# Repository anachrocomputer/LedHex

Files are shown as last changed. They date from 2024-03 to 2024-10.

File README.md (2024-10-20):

# LedHex #

This repository contains several programs to run on an Arduino
and drive a display made from LEDs.

The display was made as a small-volume low-cost PCB using a design drawn in KiCad.

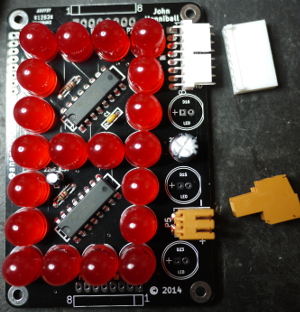
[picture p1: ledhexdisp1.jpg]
LedHexDisplay Completed PCB populated with red LEDs


## KiCadV3Pcb ##

CAD files for the schematic and PCB,
designed in 2014 using KiCad V3.
This version of KiCad is so old now that it's not practical to update the files.
At the time of writing,
KiCad is at V8.0.5 and uses a completely different set of PCB footprints from V3.
So although it's possible to update the schematic files to use the latest format
and the latest symbols,
it's difficult to map those symbols to the new footprints.
This means that the PCB layout cannot be resynchronised with the schematic.
Probably the easiest way to fix this would be to re-draw in KiCad V8.

The schematic is shown as a PDF for reference when writing software
to drive the display.

## LedHexClock ##

Very simple four-digit clock with flashing colon.
So simple, in fact,
that there's no way to set the time.

TODO: add a way to set the time.

TODO: add 12/24 hour switch.

TODO: add other types of time display, TBD.

## LedHexCount4 ##

Display a four-digit counter on four LedHex PCBs connected in a chain.
Range is 0000-FFFF (0-65535).

## LedHexLampTest4 ##

Test a four-digit chain of LedHex PCBs by lighting up all the segments
in sequence.
This is also a test of the LED power supply!

## LedHexTest ##

Simply count 0-9, A-F repeatedly on a single digit display.

## LedHexTest4 ##

Test a four-digit chain of LedHex PCBs by lighting up all the segments
in sequence.

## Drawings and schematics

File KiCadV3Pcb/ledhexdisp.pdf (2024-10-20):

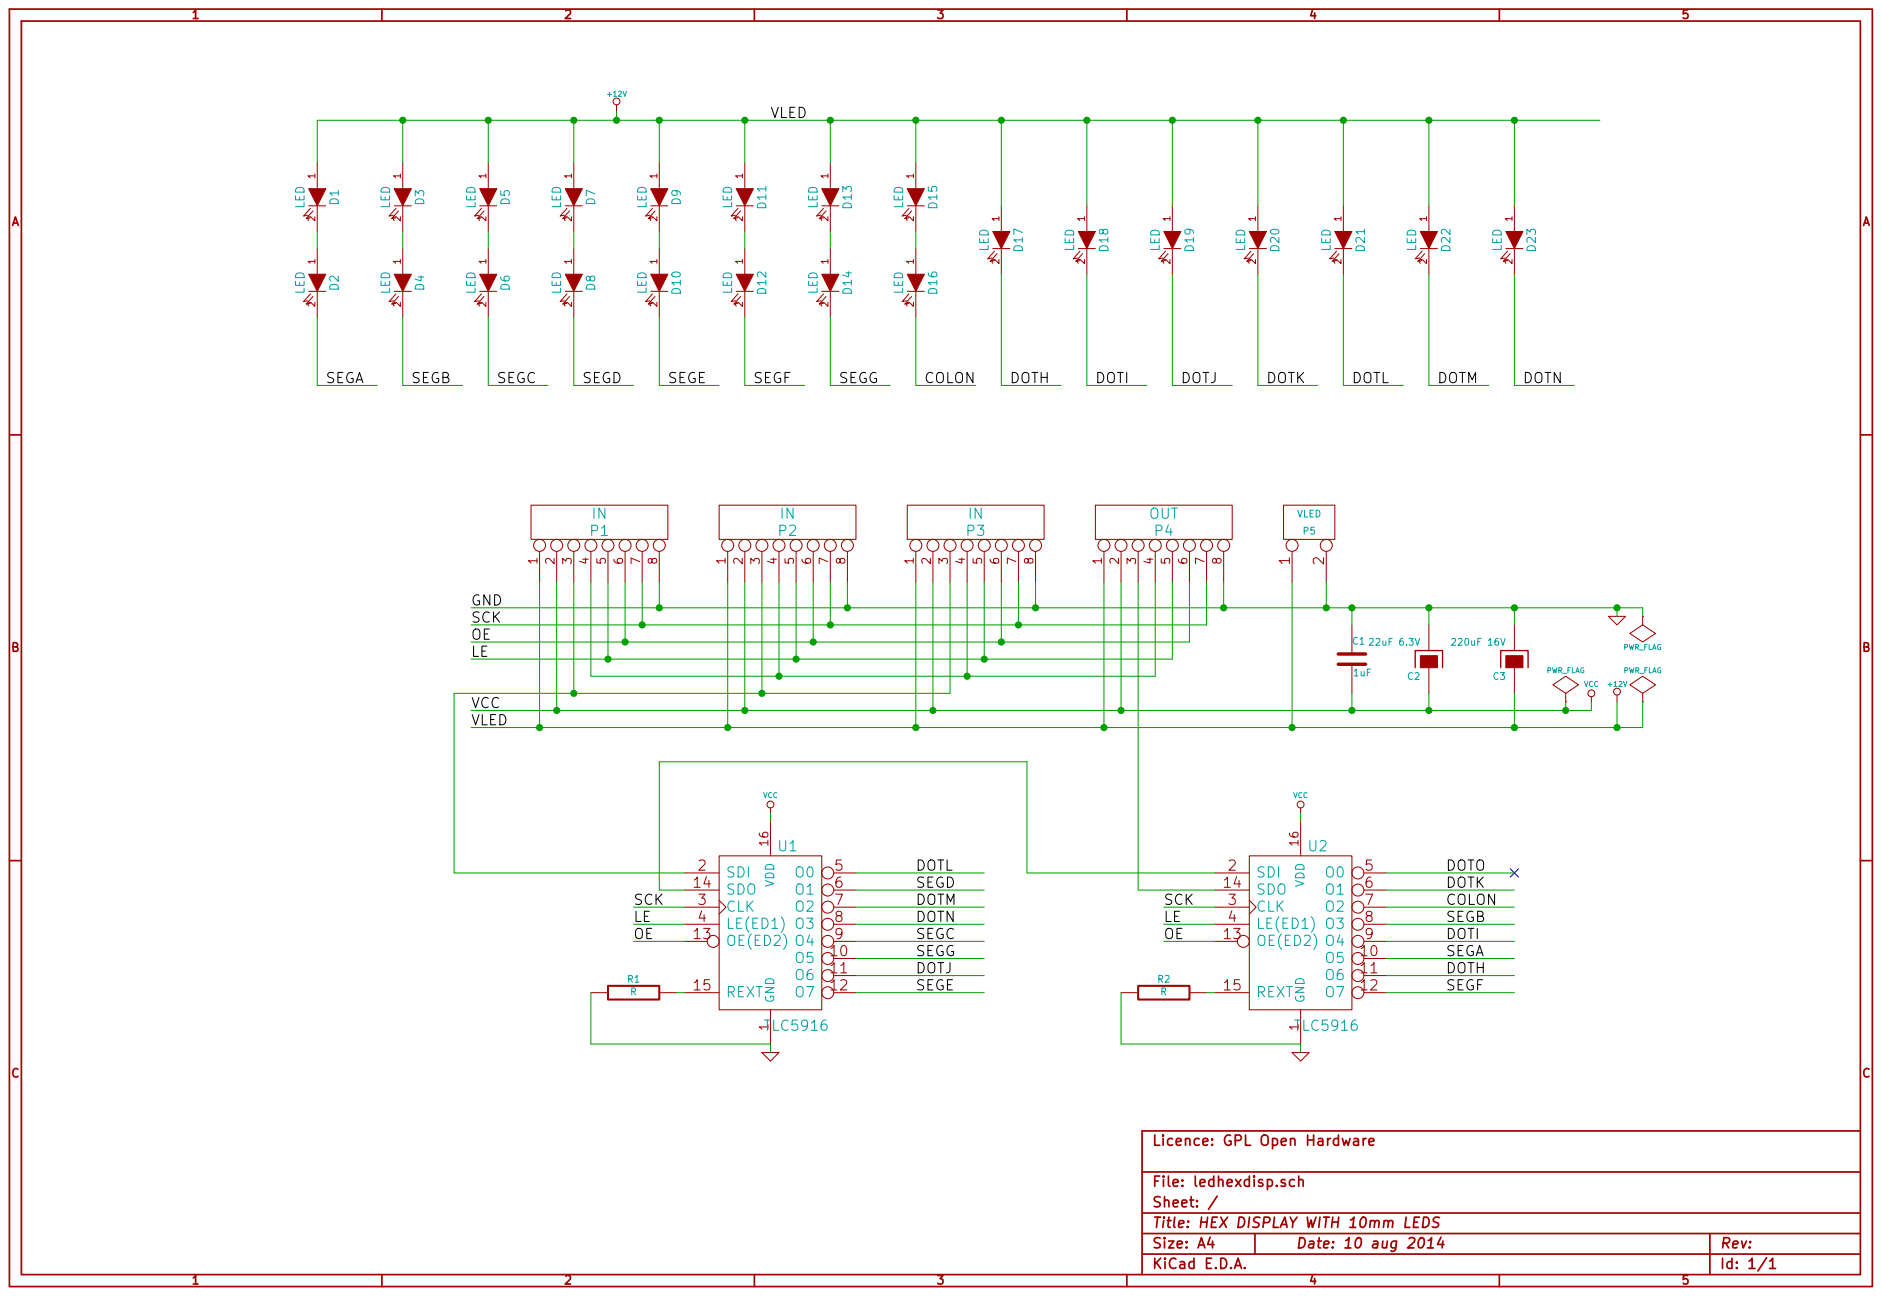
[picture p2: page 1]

Licence: GPL Open Hardware

File: ledhexdisp.sch
Sheet: /
Title: HEX DISPLAY WITH 10mm LEDS
KiCad E.D.A.

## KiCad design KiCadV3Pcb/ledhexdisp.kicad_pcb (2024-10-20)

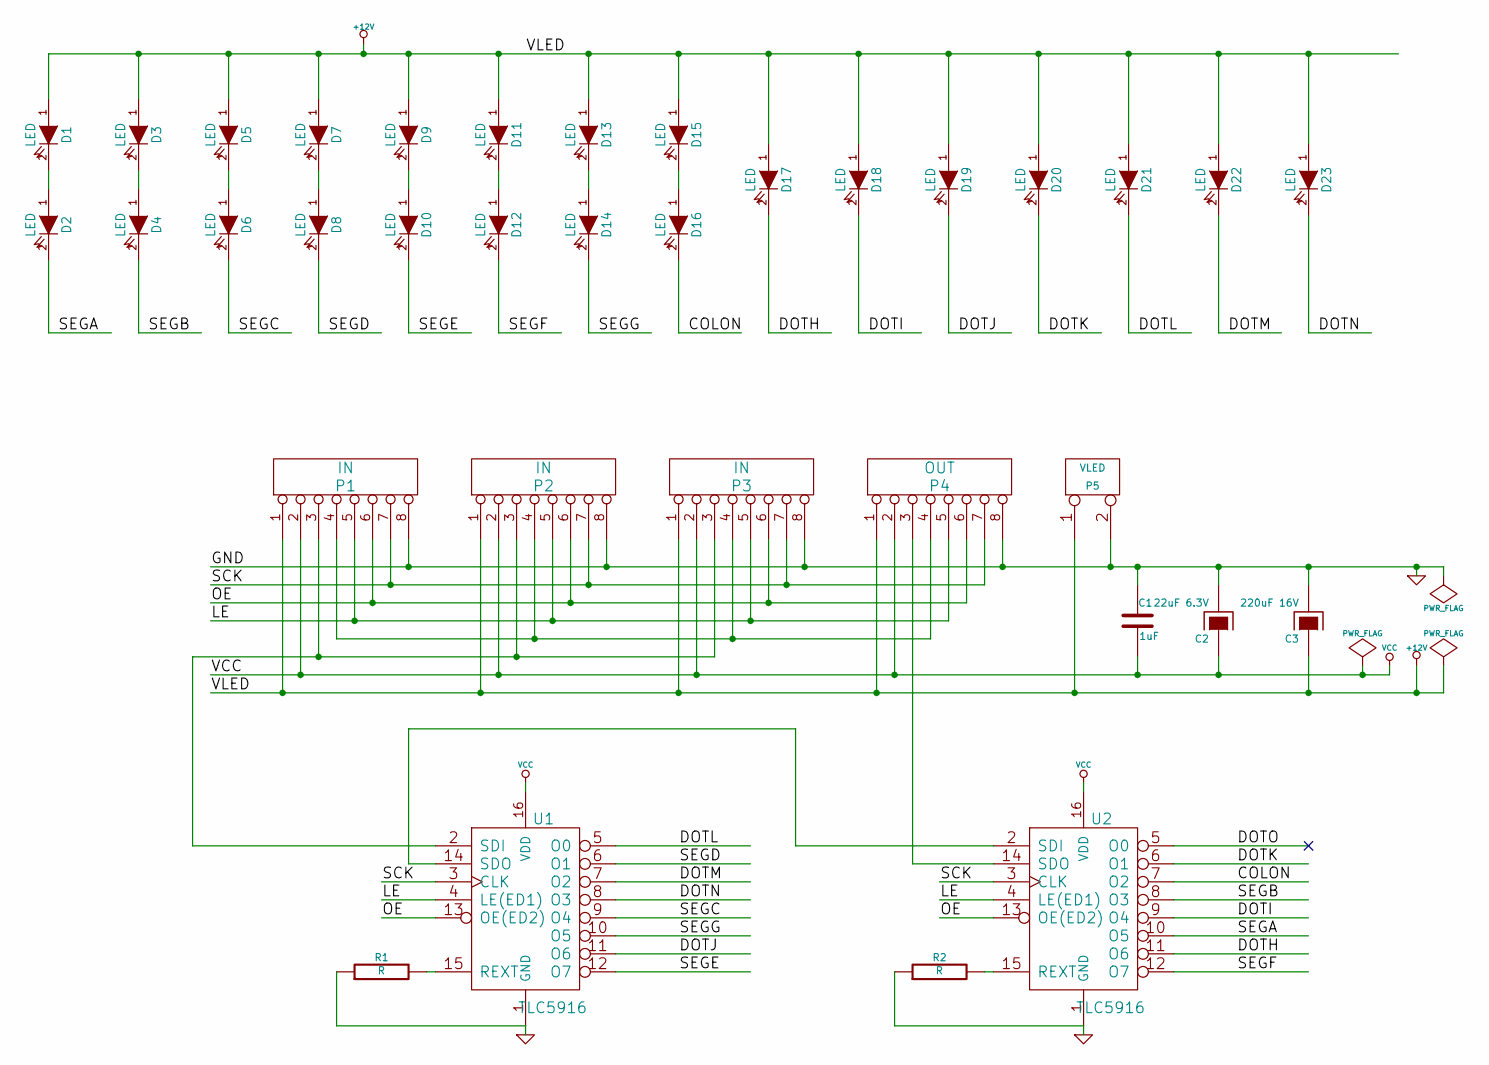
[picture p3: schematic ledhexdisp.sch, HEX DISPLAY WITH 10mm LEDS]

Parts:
C1: 1uF
C2: 22uF 6.3V
C3: 220uF 16V
D1, D2, D3, D4, D5, D6, D7, D8, D9, D10, D11, D12, D13, D14, D15, D16, D17, D18, D19, D20, D21, D22, D23: LED
P1, P2, P3: IN
P4: OUT
P5: VLED
R1, R2: R
U1, U2: TLC5916

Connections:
+12V: C3.1, D1.1 (A), D3.1 (A), D5.1 (A), D7.1 (A), D9.1 (A), D11.1 (A), D13.1 (A), D15.1 (A), D17.1 (A), D18.1 (A), D19.1 (A), D20.1 (A), D21.1 (A), D22.1 (A), D23.1 (A), P1.1, P2.1, P3.1, P4.1, P5.1
/COLON: D16.2 (K), U2.7 (O2)
/DOTH: D17.2 (K), U2.11 (O6)
/DOTI: D18.2 (K), U2.9 (O4)
/DOTJ: D19.2 (K), U1.11 (O6)
/DOTK: D20.2 (K), U2.6 (O1)
/DOTL: D21.2 (K), U1.5 (O0)
/DOTM: D22.2 (K), U1.7 (O2)
/DOTN: D23.2 (K), U1.8 (O3)
/LE: P1.5, P2.5, P3.5, P4.5, U1.4 (LE(ED1)), U2.4 (LE(ED1))
/OE: P1.6, P2.6, P3.6, P4.6, U1.13 (OE(ED2)), U2.13 (OE(ED2))
/SCK: P1.7, P2.7, P3.7, P4.7, U1.3 (CLK), U2.3 (CLK)
/SEGA: D2.2 (K), U2.10 (O5)
/SEGB: D4.2 (K), U2.8 (O3)
/SEGC: D6.2 (K), U1.9 (O4)
/SEGD: D8.2 (K), U1.6 (O1)
/SEGE: D10.2 (K), U1.12 (O7)
/SEGF: D12.2 (K), U2.12 (O7)
/SEGG: D14.2 (K), U1.10 (O5)
GND: C1.1, C2.2, C3.2, P1.8, P2.8, P3.8, P4.8, P5.2 (PM), R1.1, R2.1, U1.1 (GND), U2.1 (GND)
unnamed: D5.2 (K), D6.1 (A)
unnamed: D3.2 (K), D4.1 (A)
unnamed: R2.2, U2.15 (REXT)
unnamed: D15.2 (K), D16.1 (A)
unnamed: D13.2 (K), D14.1 (A)
unnamed: D11.2 (K), D12.1 (A)
unnamed: D9.2 (K), D10.1 (A)
unnamed: D7.2 (K), D8.1 (A)
unnamed: R1.2, U1.15 (REXT)
unnamed: P4.3, U2.14 (SDO)
unnamed: P1.3, P2.3, P3.3, U1.2 (SDI)
unnamed: U1.14 (SDO), U2.2 (SDI)
unnamed: P1.4, P2.4, P3.4, P4.4
unnamed: D1.2 (K), D2.1 (A)
VCC: C1.2, C2.1, P1.2, P2.2, P3.2, P4.2, U1.16 (VDD), U2.16 (VDD)

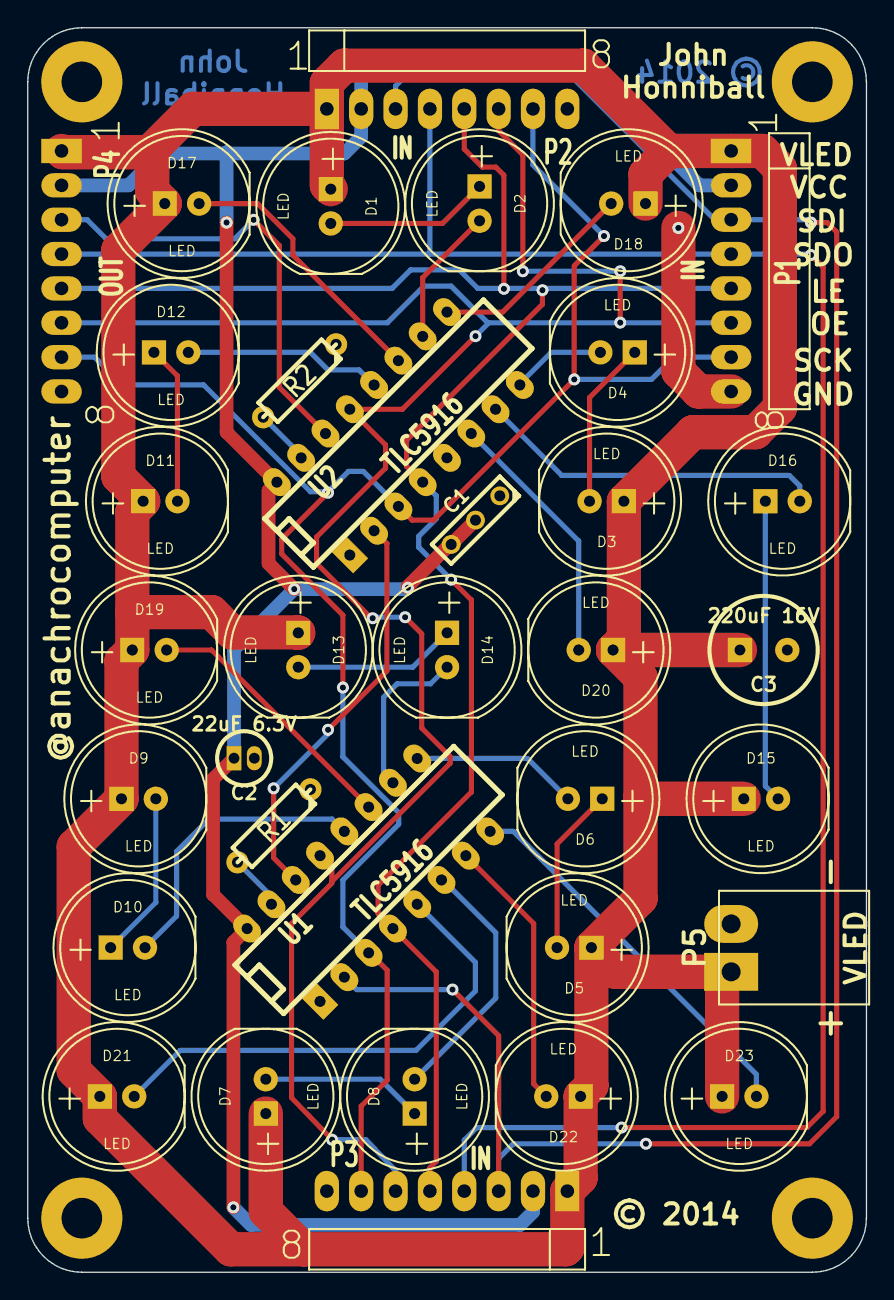
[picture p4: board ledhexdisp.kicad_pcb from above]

Board: 2 copper layers, 62.0 x 92.0 mm, 35 parts (0 on the bottom side), 35 nets.

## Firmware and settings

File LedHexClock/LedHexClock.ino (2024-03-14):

/* LedHexClock --- display a four-digit clock             2018-02-18 */
/* Copyright (c) 2018 John Honniball                                 */

#define NDIGITS    (4)   // This program uses a four-digit display

// Pin connections from LED board to Arduino board
// 1 VLED +5V (LED power, OK to use Arduino +5V for a single digit)
// 2 VCC  +5V (TLC5916 chip power)
// 3 SDI  D11 (Serial Data In on TLC5916)
// 4 SDO  no connection (Serial Data out on TLC5916, unused)
// 5 LE   D10 (Latch Enable on TLC5916)
// 6 OE   GND (Output Enable, unused in this test, GND to enable)
// 7 SCK  D13 (Serial Clock to TLC5916)
// 8 GND  GND (Ground to both LEDs and chip)
//
#define LE_PIN 10   // Arduino digital pin 10
#define SDA_PIN 11  // Arduino digital pin 11
#define SCK_PIN 13  // Arduino digital pin 13
/* OE pin grounded */

// 'F' is #defined as a macro by Arduino framework. Use an int instead
const int F = (1 << 14);

// Usual 7-segment names
#define A  (1 << 8)
#define B  (1 << 0)
#define C  (1 << 2)
#define D  (1 << 4)
#define E  (1 << 11)
//#define F  (1 << 14)
#define G  (1 << 10)
#define DP (1 << 12)

// Additional dot names
#define H (1 << 1)
#define I (1 << 3)
#define J (1 << 9)
#define K (1 << 6)
#define L (1 << 15)
#define M (1 << 13)
#define COLON (1 << 5)

// LED layout on PCB:
//
//     H C C I
//     B     D
//     B     D
//     J G G K
//     A     E
//     A     E
//     L F F M DP

// Table of 14-segment digits 0-9 and A-F
const unsigned int HDSPsegtab[16] = {
  A | B | C | D | E | F | J | K,         // 0
  D | E | I | K | M,                     // 1
  A | C | D | F | G | H | L | M,         // 2
  C | D | E | F | G | H | L,             // 3
  B | D | E | G | H | J | K | M,         // 4
  B | C | E | F | G | H | I | J | L,     // 5
  A | B | C | E | F | G | J,             // 6
  C | D | E | H | I | K | M,             // 7
  A | B | C | D | E | F | G,             // 8
  B | C | D | E | F | G | K,             // 9
  A | B | C | D | E | G | J | K | L | M, // A
  A | B | C | D | E | F | G | H | J | L, // B
  A | B | C | F | I | J | M,             // C
  A | B | C | D | E | F | H | J | K | L, // D
  A | B | C | F | G | H | I | J | L | M, // E
  A | B | C | G | H | I | J | L          // F
};


void setup(void)
{
  pinMode(LE_PIN, OUTPUT);
  pinMode(SDA_PIN, OUTPUT);
  pinMode(SCK_PIN, OUTPUT);
  
  digitalWrite(LE_PIN, LOW);
  digitalWrite(SCK_PIN, LOW);
}


void loop(void)
{
  int d;
  unsigned int hours = 12, minutes = 0;
  unsigned int frames = 0;
  char timstr[8];
  unsigned int digit;
  unsigned int segs[NDIGITS];           // 16-bit unsigned binary

  for (;;) {
    snprintf(timstr, sizeof (timstr), "%02d%02d", hours, minutes);
    
    for (d = 0; d < NDIGITS; d++) {
      digit = timstr[d] - '0';
        
      segs[d] = HDSPsegtab[digit];   // Pick up segment pattern from table
    }

    if (frames > 25)
      segs[1] |= COLON;

    LedHex_send(segs, NDIGITS);     // Send to displays
    
    minutes++;

    if (minutes >= 60) {
      minutes = 0;
      hours++;

      if (hours >= 24)
        hours = 0;
    }

    frames++;
    if (frames >= 50)
      frames = 0;

    delay(20);                      // Update at 50Hz
  }
}


/* LedHex_send --- send 'ndig' 16-bit patterns to the LED driver chip */

void LedHex_send(const unsigned int leds[], const int ndig)
{
  // Straightforward implementation using digitalWrite(). Could be made
  // faster by using direct port I/O or SPI hardware.
  int i;
  int d;
  
  digitalWrite(LE_PIN, LOW);
  digitalWrite(SCK_PIN, LOW);

  // Send 16 bits to each pair of TLC5916 chips per digit
  for (d = 0; d < ndig; d++) {
    for (i = 0; i < 16; i++) {
      // Send one bit on SDA pin
      if (leds[d] & (1u << i))
        digitalWrite(SDA_PIN, HIGH);
      else
        digitalWrite(SDA_PIN, LOW);
      
      delayMicroseconds(1);

      // One microsecond HIGH pulse on SCK to clock the bit along
      digitalWrite(SCK_PIN, HIGH);
      
      delayMicroseconds(1);
      
      digitalWrite(SCK_PIN, LOW);  
    }
  }

  // One microsecond HIGH pulse on LE to latch all bits into all the digits
  digitalWrite(LE_PIN, HIGH);
  
  delayMicroseconds(1);
    
  digitalWrite(LE_PIN, LOW);
}

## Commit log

2018-02-16 Initial commit of test program for the LED hex display PCB. All it does is count up in hex 0-9, A-F continuously.
2018-02-17 Add some more test programs for the LED hex display PCB. All of these programs work on the 4-digit display (4 PCBs wired in a daisy-chain).
2024-03-14 Add LedHexClock.
    Embryonic Arduino sketch for a four-digit clock with flashing colon.
2024-10-20 Add KiCad PCB design files.
    At last, ten years after I designed it all. Shame it's now so old that it's almost no use. But the PCB layout can still be manufactured, if I need more boards.
    [ledhexdisp.kicad_pcb, ledhexdisp.sch]
2024-10-20 Add photo of PCB.
    Just the main digit with red LEDs.

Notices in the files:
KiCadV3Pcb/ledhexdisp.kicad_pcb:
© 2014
